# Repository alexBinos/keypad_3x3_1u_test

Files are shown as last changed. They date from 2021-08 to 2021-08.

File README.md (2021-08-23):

# keypad_3x3_1u_test

Sharing progress on the 3x3 macro keypad...

## Assembly notes

1. RGB LEDs
   - Pin 1 is marked on the PCB in silkscreen, note that the odd pin on the LED package is GND (pin 3).
   - The LEDs are designed to be placed on the back side of the PCB, facing towards the front, through the cut out.
   - To assist PCB routing, **not all LEDs are oriented in the same direction**, pay close attention to the pin 1 markings on each LED footprint.
   - The cutouts for the bottom most LEDs (D13, D16, D19) was deliberately made 0.4mm wider than the others to test the PCB footprint. This footprint wont be used on future designs.

<br/>

2. Component orientations
   - The pin 1 marker on the KC2016K 16MHz crystal oscillator (X1) and the SRV05-4 TVS diode array (U3) were not placed.
   - With the USB connector facing up:
      - Pin 1 of X1 is the **top right** pad.
      - Pin 1 of U3 is the **top left** pad.

<br/>

3. Entering the bootloader
   - Through the ISP interface, disable the HWBE fuse and enable the BOOTRST fuse.
   - Flash the Caterina bootloader
   - See section 27 of the ATMEGA32U4 datasheet for more details.

<br/>

4. Non-critical hardware bugs
   - The series termination resistor for the RGB LEDs was not placed, the LEDS still work but this may affect their reliability.
   - Pads for the reset switch are slightly too small for the switch provided but you can still make it fit

<br/>

5. If you find any more issues or have feedback for the next revision let me know

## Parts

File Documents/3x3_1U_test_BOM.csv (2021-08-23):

Id | Designator | Package | Quantity | Designation
1 | SW11 | SW_SPST_B3U-1000P | 1 | SW_Push
2 | U2 | TCR2EF33_SOT25 | 1 | TCR2EF33
3 | FB3 FB2 FB1 | L_0805_2012Metric | 3 | Ferrite_Bead
4 | D19 D16 D13 D18 D17 D15 D12 D11 D14 | SK6812-MINI-E | 9
5 | L1 | SMM2012E | 1 | L_Core_Iron_Coupled_1423
6 | J2 | USB_C_Receptacle_GCT_USB4085 | 1 | USB_C_Receptacle_USB2.0
7 | X1 | KC2016K | 1 | KC2016K
8 | U3 | SOT-23-6 | 1 | SRV05-4
9 | U1 | TQFP-44_10x10mm_P0.8mm | 1 | ATmega32U4-AU
10 | TP3 TP2 TP1 | TestPoint_Pad_D1.0mm | 3 | TestPoint
11 | SW9 SW8 SW7 SW6 SW5 SW4 SW3 SW2 SW1 | CherryMX_1.00u_PCB_KailhSocket | 9
12 | SW10 | RotaryEncoder_Alps_EC11E-Switch_Vertical_H20mm | 1 | Rotary_Encoder_Switch
13 | R17 R16 R8 R5 | R_0603_1608Metric | 3 | 330R
14 | R15 R14 | R_0603_1608Metric | 2 | 22R
15 | R13 R12 | R_0603_1608Metric | 2 | OPT
16 | R11 R9 | R_0603_1608Metric | 2 | 5K1
17 | R10 R7 R6 R4 R3 | R_0603_1608Metric | 5 | 1K
18 | R2 R1 | R_0603_1608Metric | 2 | 10K
19 | J1 | PinHeader_2x03_P2.54mm_Vertical_SMD | 1 | Conn_02x03_Odd_Even
20 | D22 D21 D20 | D_0603_1608Metric | 3 | LED
21 | D10 D9 D8 D7 D6 D5 D4 D3 D2 D1 | D_SOD-323 | 10
22 | C19 C15 C14 C13 C11 C10 C9 C8 C7 C6 C5 C4 C3 C2 C1 | C_0603_1608Metric | 15 | 100nF
23 | C18 C16 C12 | C_0603_1608Metric | 3 | 1uF
24 | C17 | C_0603_1608Metric | 1 | 10uF

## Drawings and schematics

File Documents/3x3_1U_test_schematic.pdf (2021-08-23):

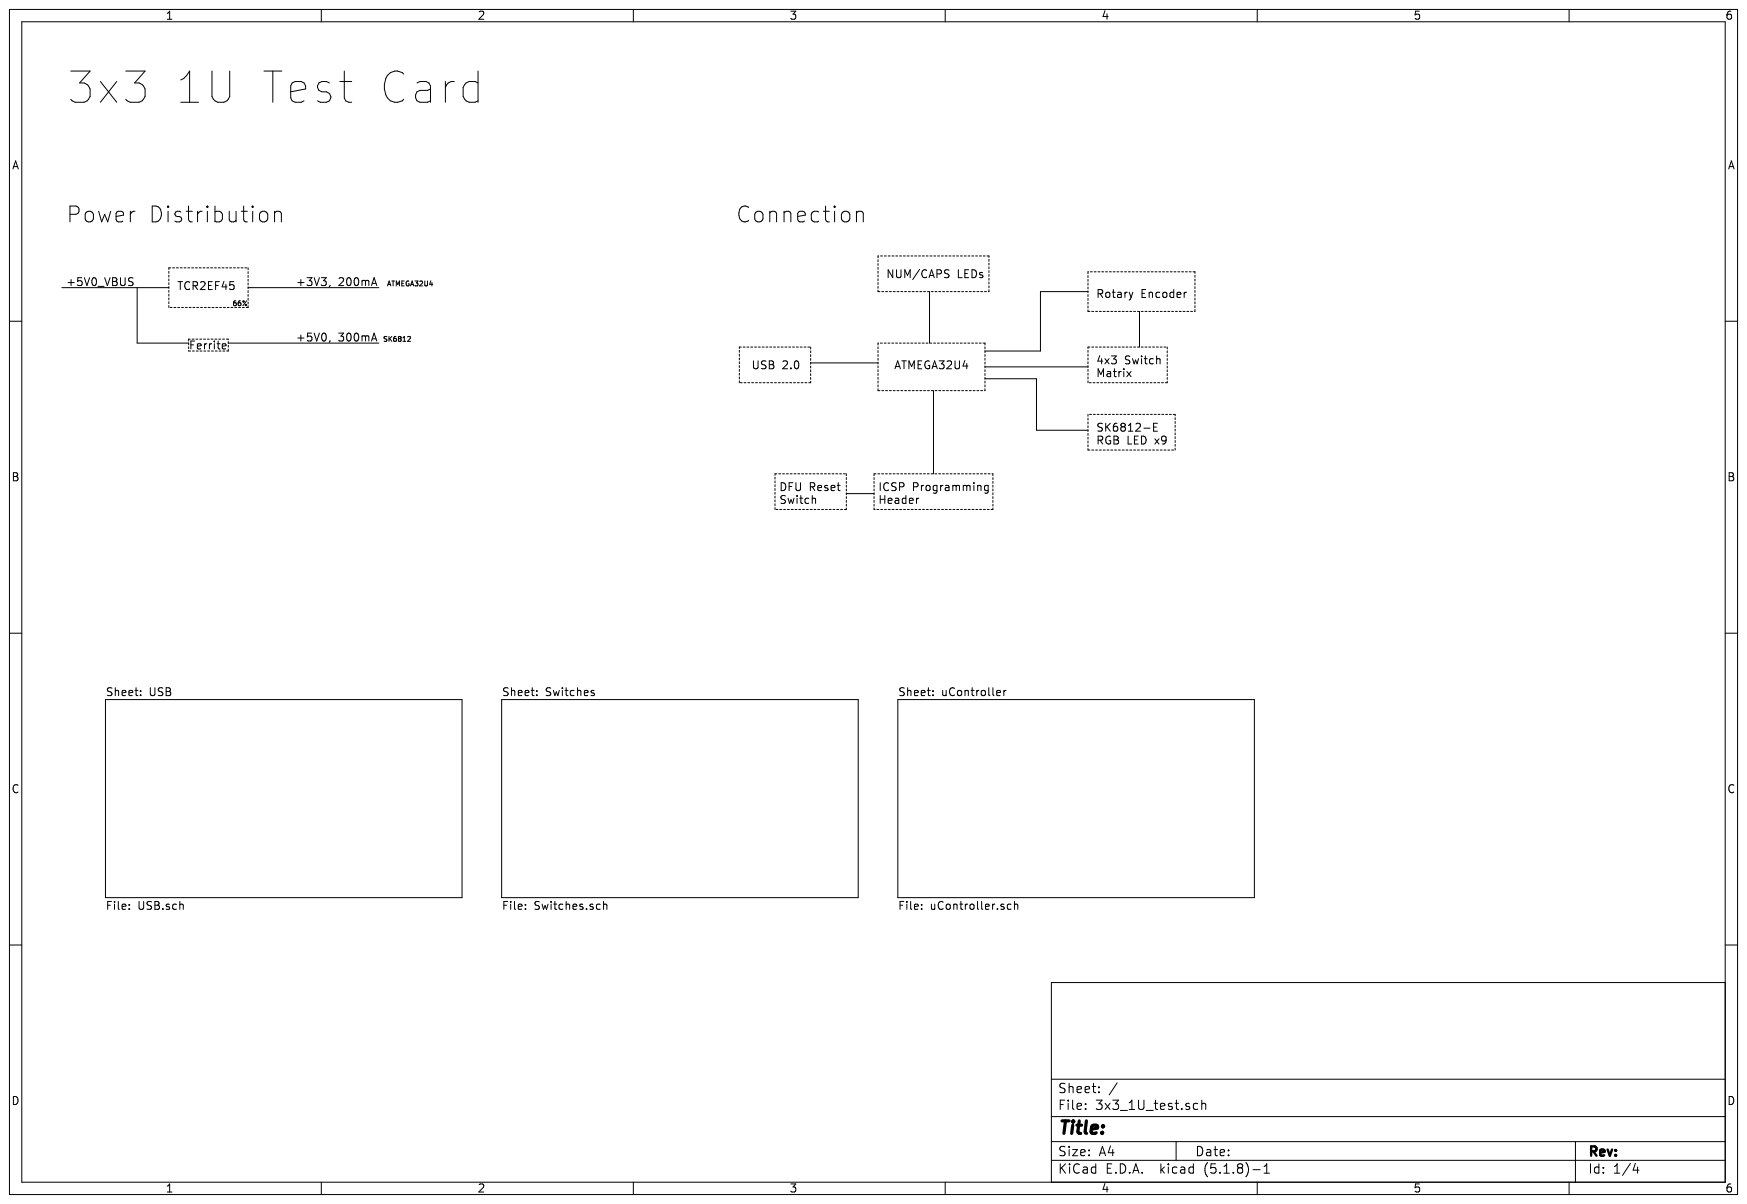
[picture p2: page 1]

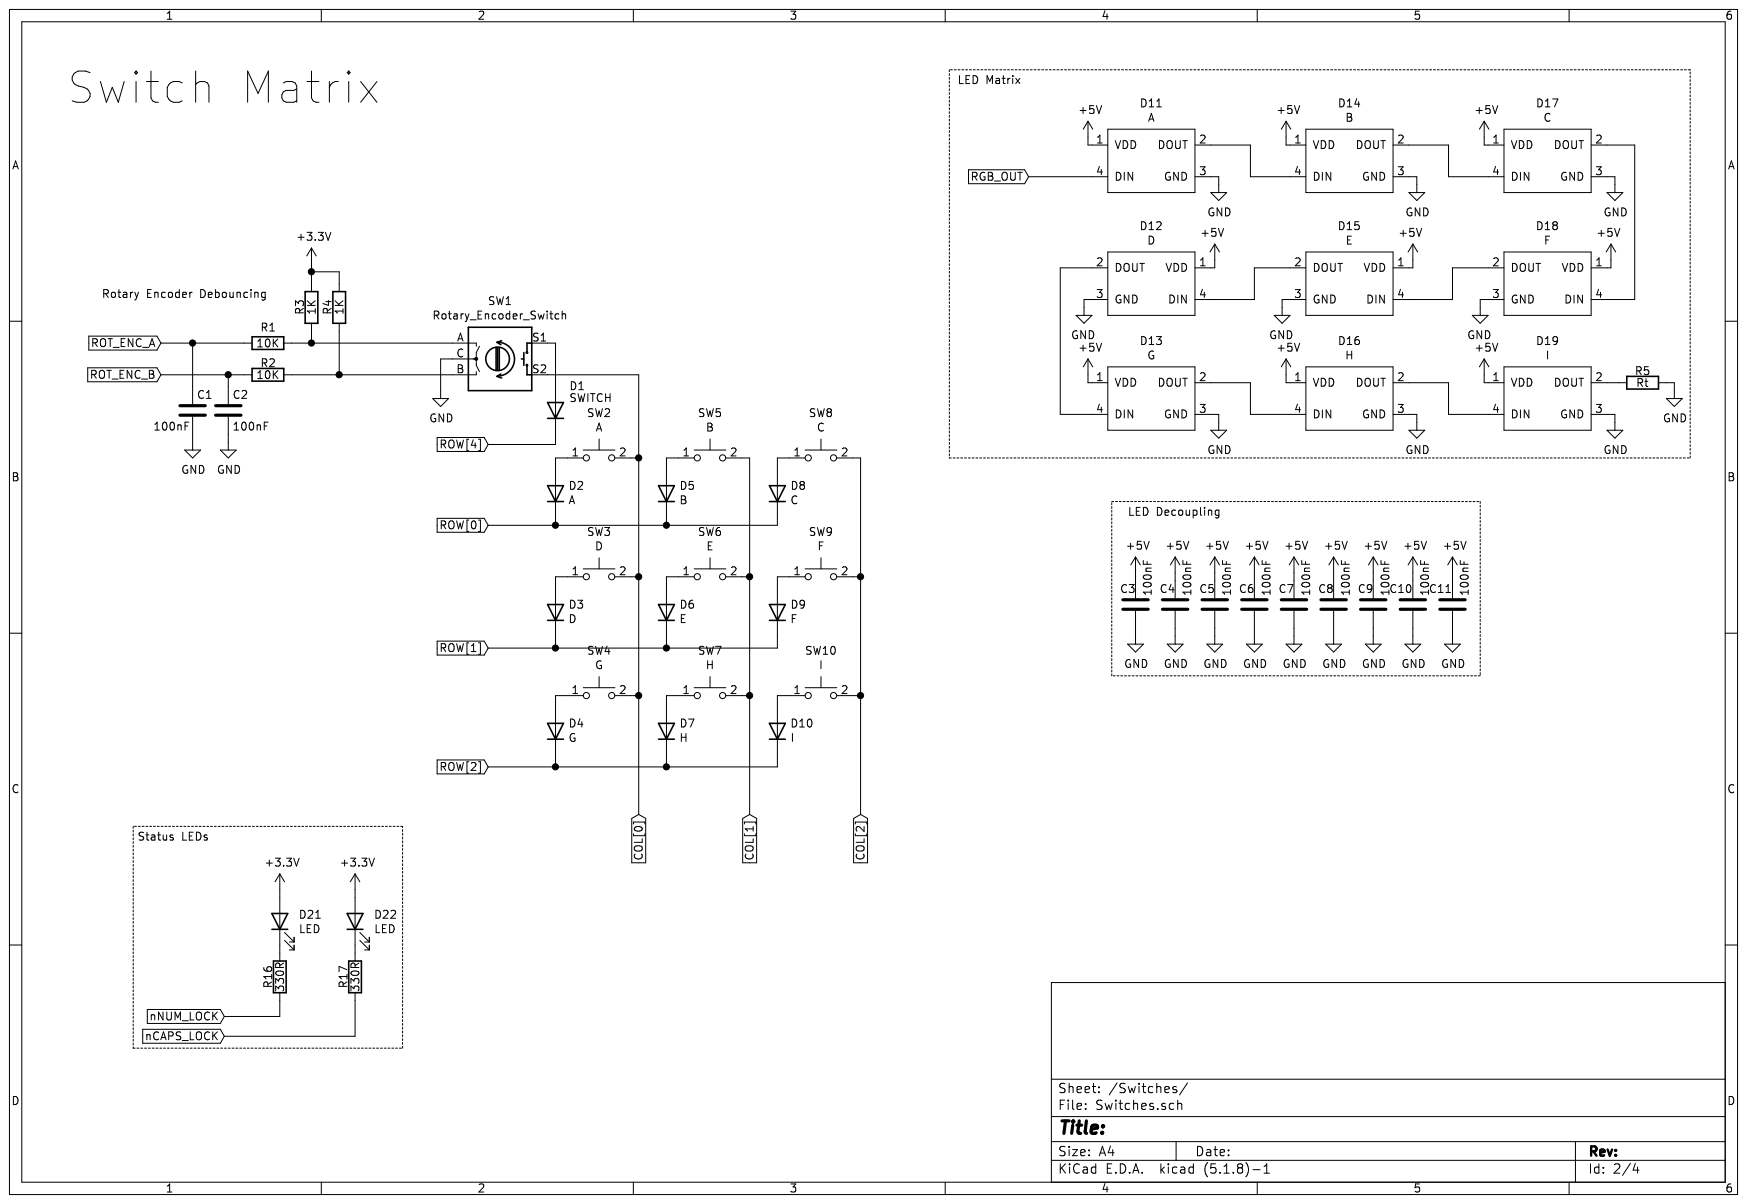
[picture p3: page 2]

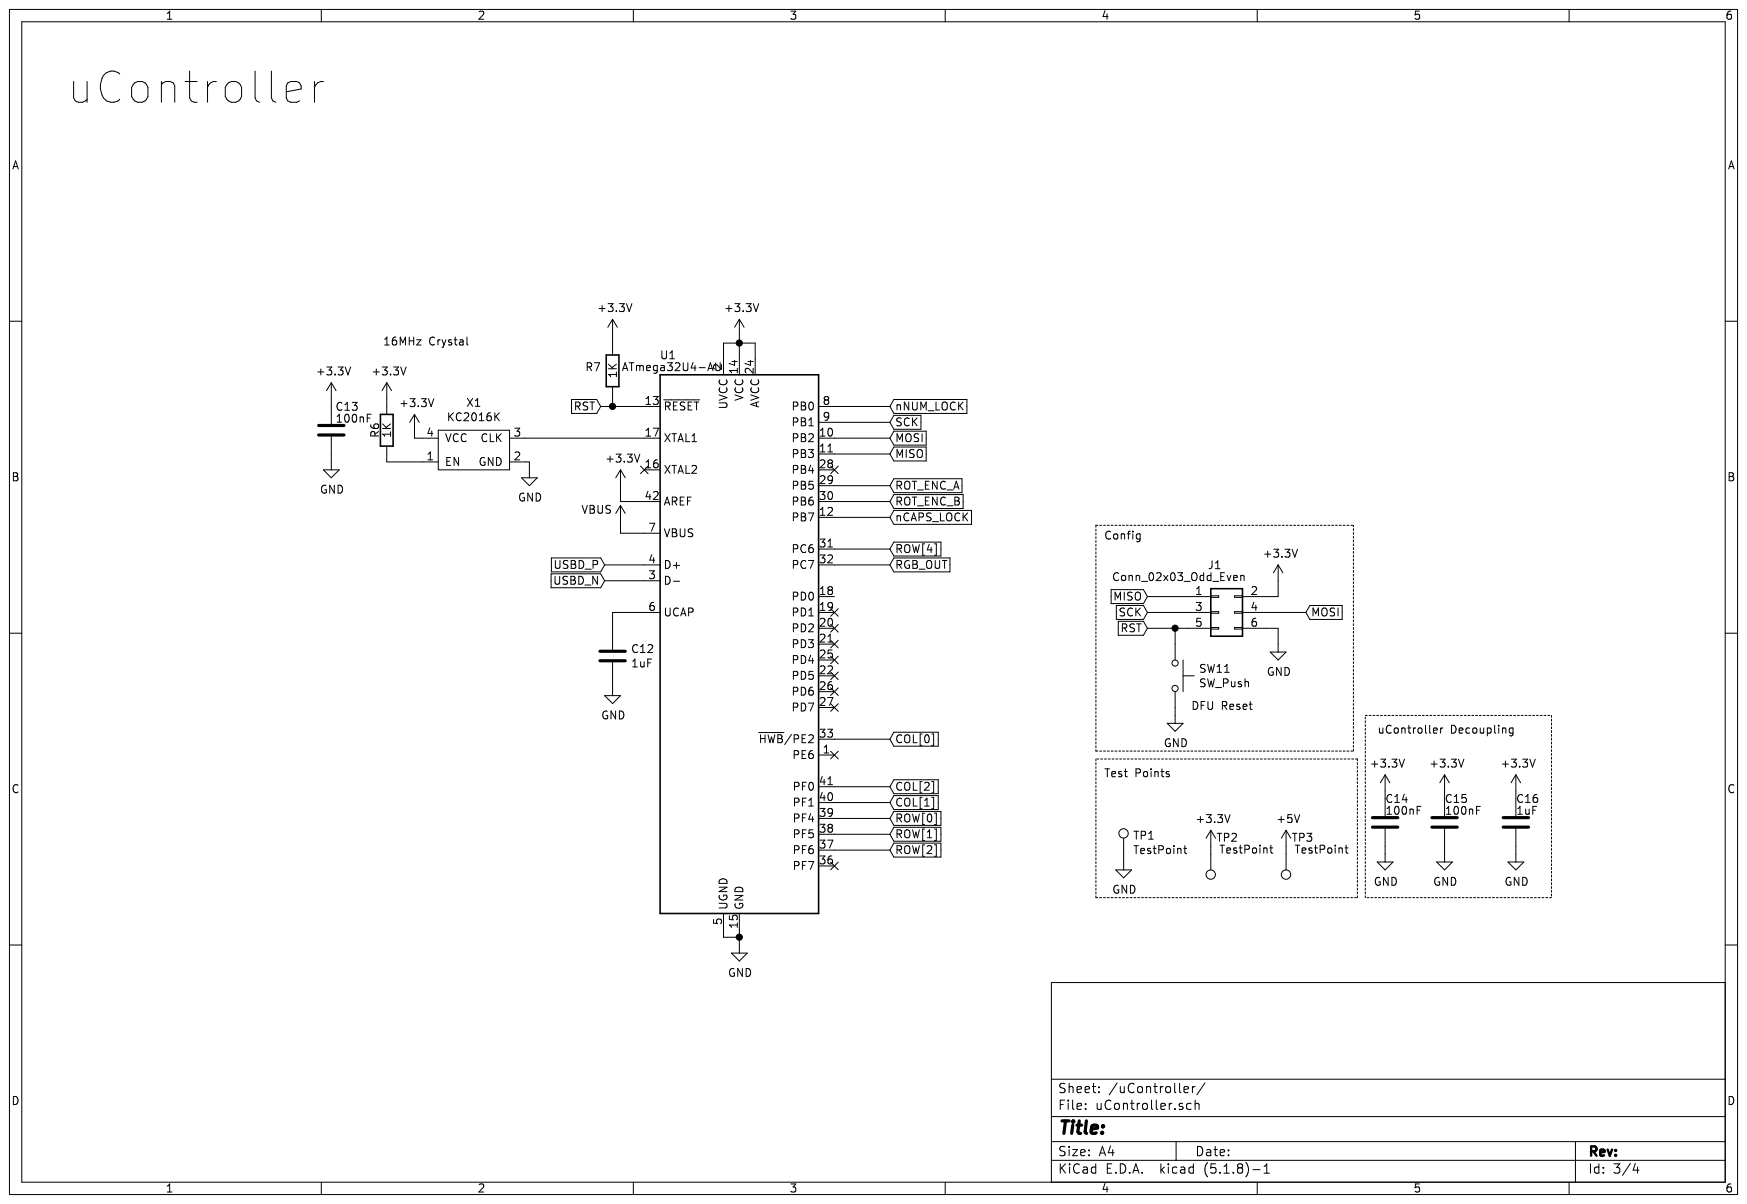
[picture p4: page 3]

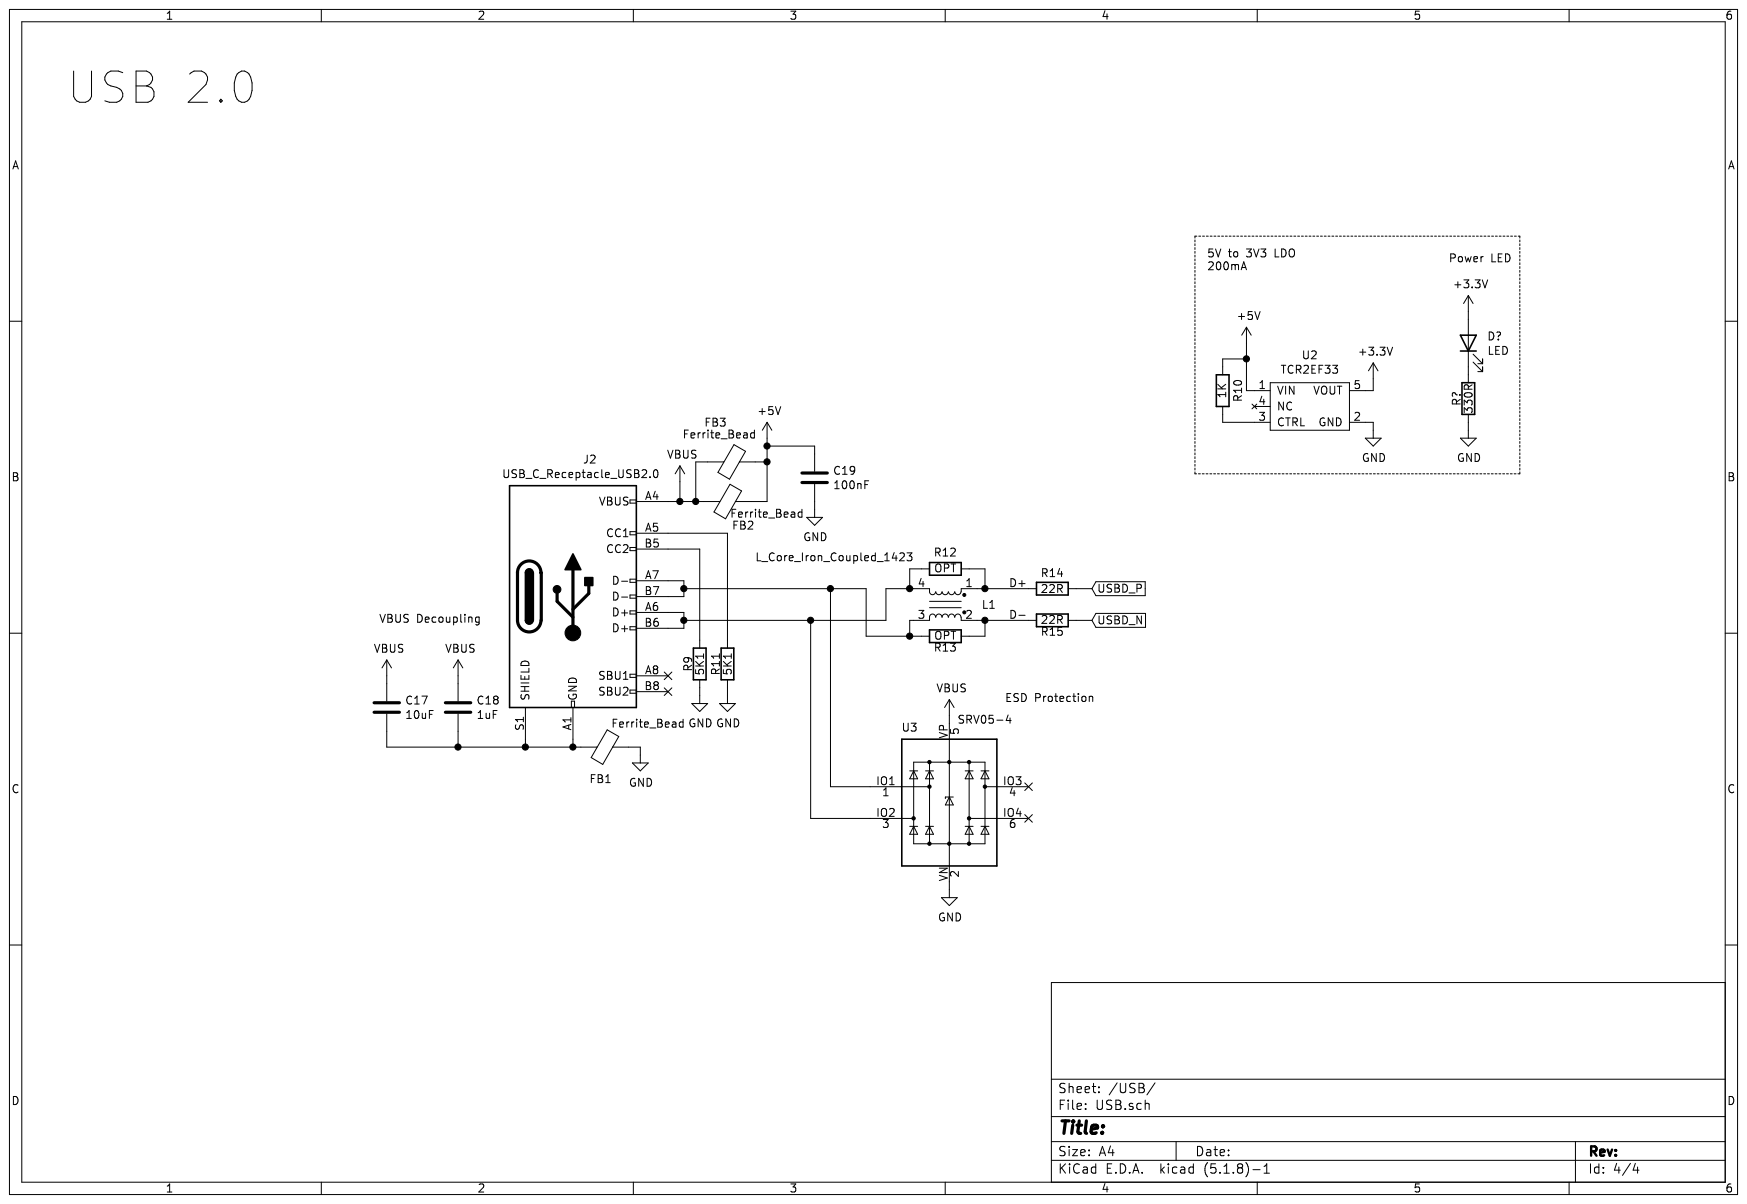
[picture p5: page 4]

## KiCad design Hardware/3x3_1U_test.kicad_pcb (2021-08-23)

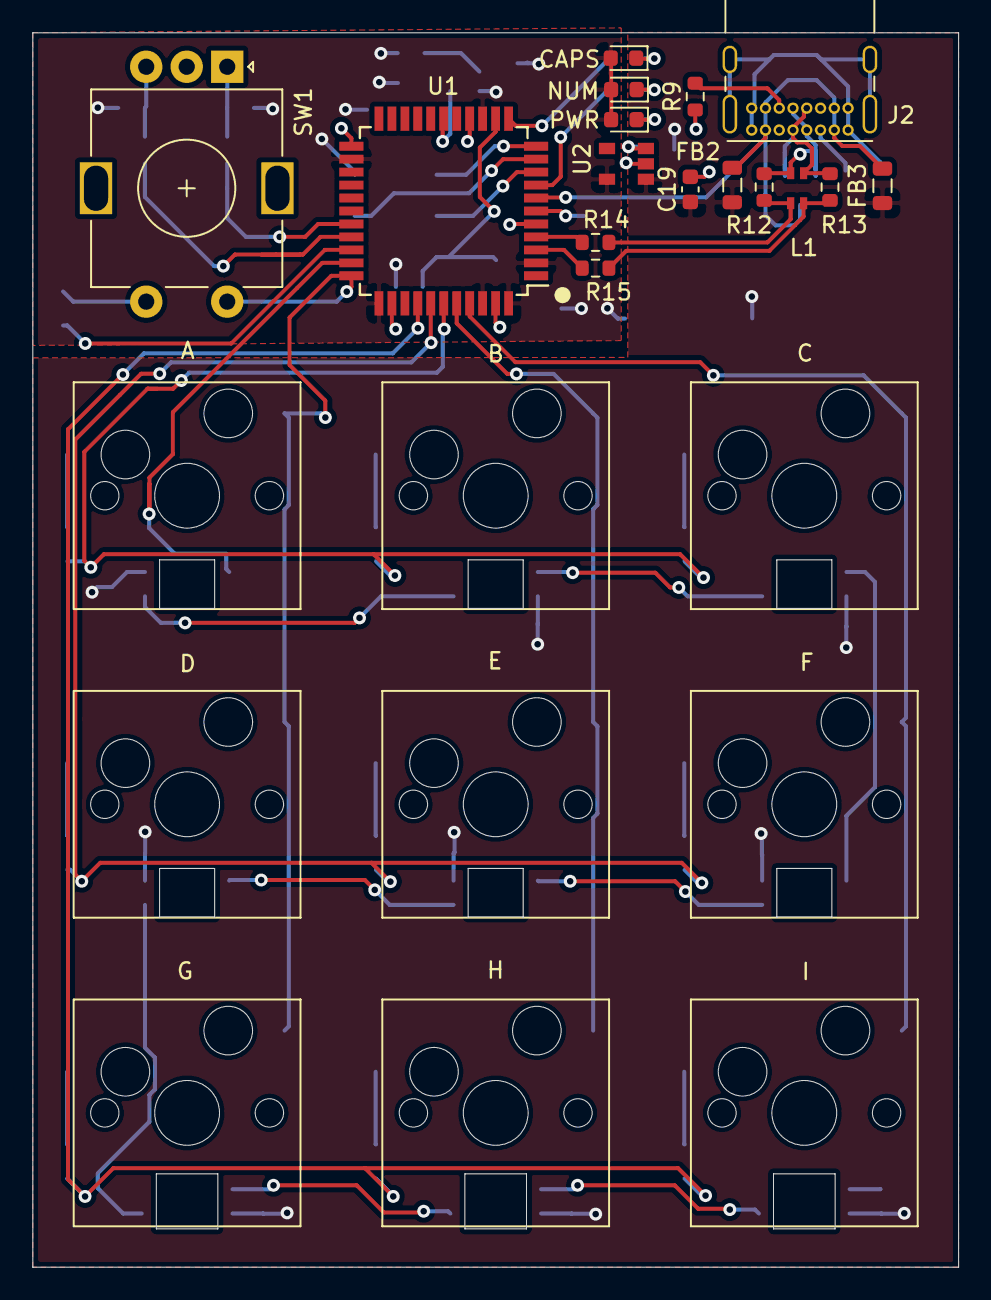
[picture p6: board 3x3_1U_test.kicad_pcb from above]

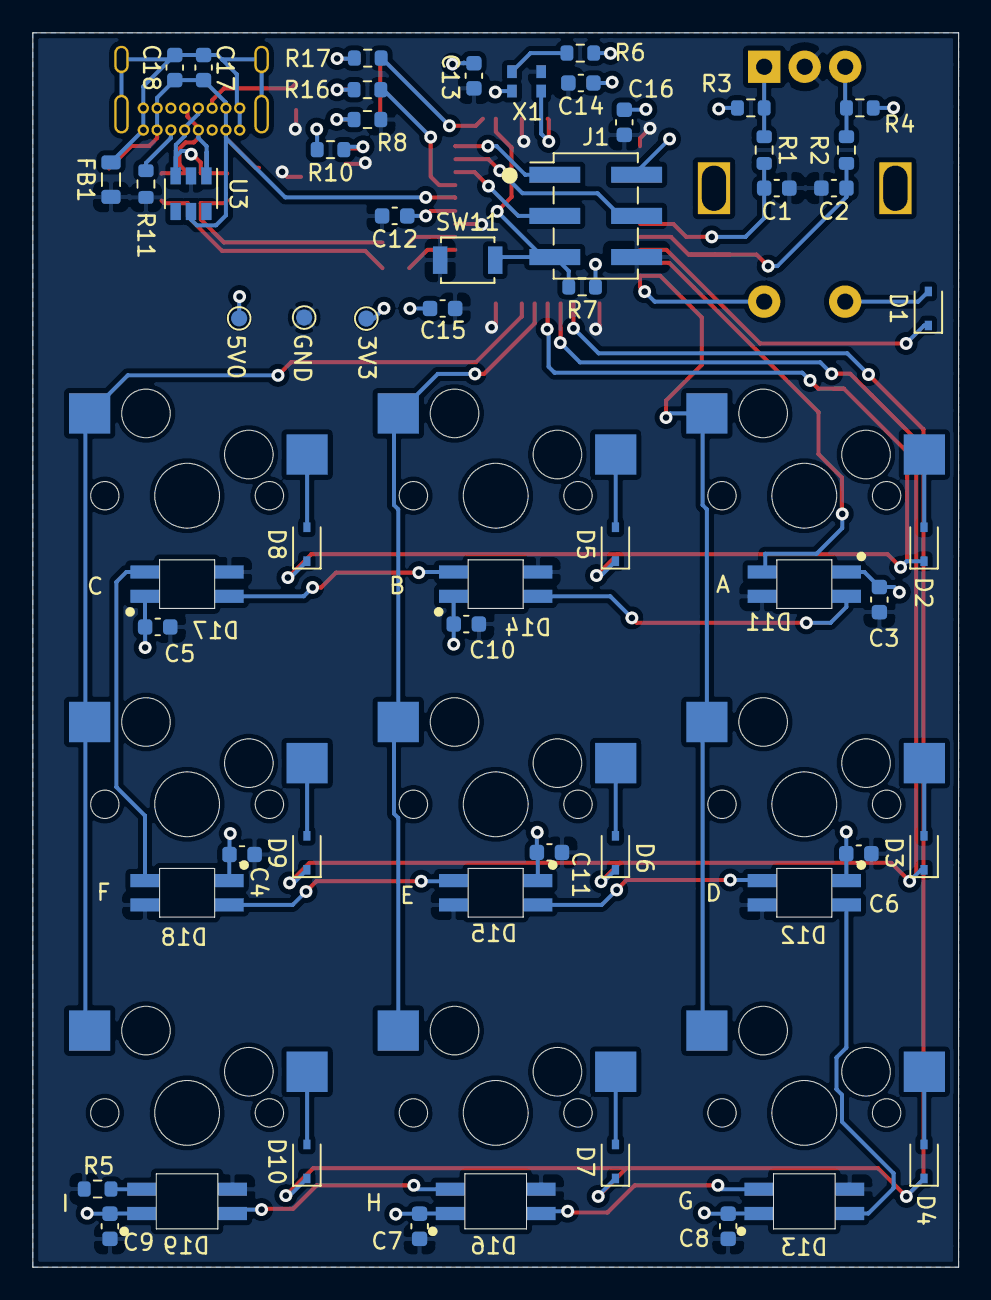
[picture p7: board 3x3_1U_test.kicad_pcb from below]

Board: 2 copper layers, 57.2 x 76.2 mm, 82 parts (48 on the bottom side), 57 nets.

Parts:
C1, C2, C3, C4, C5, C6, C7, C8, C9, C10, C11, C13, C14, C15, C19: 100nF; C_0603_1608Metric
C12, C16, C18: 1uF; C_0603_1608Metric
C17: 10uF; C_0603_1608Metric
D1: SWITCH; D_SOD-323
D2: A; D_SOD-323
D3: D; D_SOD-323
D4: G; D_SOD-323
D5: B; D_SOD-323
D6: E; D_SOD-323
D7: H; D_SOD-323
D8: C; D_SOD-323
D9: F; D_SOD-323
D10: I; D_SOD-323
D11: A; SK6812-MINI-E
D12: D; SK6812-MINI-E
D13: G; SK6812-MINI-E_0.4
D14: B; SK6812-MINI-E
D15: E; SK6812-MINI-E
D16: H; SK6812-MINI-E_0.4
D17: C; SK6812-MINI-E
D18: F; SK6812-MINI-E
D19: I; SK6812-MINI-E_0.4
D20, D21, D22: LED; D_0603_1608Metric
FB1, FB2, FB3: Ferrite_Bead; L_0805_2012Metric
J1: Conn_02x03_Odd_Even; PinHeader_2x03_P2.54mm_Vertical_SMD
J2: USB_C_Receptacle_USB2.0; USB_C_Receptacle_GCT_USB4085
L1: L_Core_Iron_Coupled_1423; SMM2012E
R1, R2: 10K; R_0603_1608Metric
R3, R4, R6, R7, R10: 1K; R_0603_1608Metric
R5: Rt; R_0603_1608Metric
R8, R16, R17: 330R; R_0603_1608Metric
R9, R11: 5K1; R_0603_1608Metric
R12, R13: OPT; R_0603_1608Metric
R14, R15: 22R; R_0603_1608Metric
SW1: Rotary_Encoder_Switch; RotaryEncoder_Alps_EC11E-Switch_Vertical_H20mm
SW2: A; CherryMX_1.00u_PCB_KailhSocket
SW3: D; CherryMX_1.00u_PCB_KailhSocket
SW4: G; CherryMX_1.00u_PCB_KailhSocket
SW5: B; CherryMX_1.00u_PCB_KailhSocket
SW6: E; CherryMX_1.00u_PCB_KailhSocket
SW7: H; CherryMX_1.00u_PCB_KailhSocket
SW8: C; CherryMX_1.00u_PCB_KailhSocket
SW9: F; CherryMX_1.00u_PCB_KailhSocket
SW10: I; CherryMX_1.00u_PCB_KailhSocket
SW11: SW_Push; SW_SPST_B3U-1000P
TP1, TP2, TP3: TestPoint; TestPoint_Pad_D1.0mm
U1: ATmega32U4-AU; TQFP-44_10x10mm_P0.8mm
U2: TCR2EF33; TCR2EF33_SOT25
U3: SRV05-4; SOT-23-6
X1: KC2016K

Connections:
+3V3: C13.1, C14.1, C15.1, C16.1, D20.2, D21.2, D22.2, J1.2, R3.1, R4.1, R6.2, R7.1, TP2.1, U1.2, U1.14, U1.24, U1.34, U1.42, U1.44, U2.5, X1.4
+5V: C3.1, C4.1, C5.1, C6.1, C7.1, C8.1, C9.1, C10.1, C11.1, C19.1, D11.1, D12.1, D13.1, D14.1, D15.1, D16.1, D17.1, D18.1, D19.1, FB2.1, FB3.1, R10.2, TP3.1, U2.1
/USB/D+: L1.1, R12.1, R14.2
/USB/D-: L1.2, R13.1, R15.2
COL[0]: SW1.S2, SW2.2, SW3.2, SW4.2, U1.33
COL[1]: SW5.2, SW6.2, SW7.2, U1.40
COL[2]: SW8.2, SW9.2, SW10.2, U1.41
GND: C1.2, C2.2, C3.2, C4.2, C5.2, C6.2, C7.2, C8.2, C9.2, C10.2, C11.2, C12.2, C13.2, C14.2, C15.2, C16.2, C19.2, D11.3, D12.3, D13.3, D14.3, D15.3, D16.3, D17.3, D18.3, D19.3, FB1.1, J1.6, R5.2, R8.1, R9.1, R11.1, SW1.C, SW11.2, TP1.1, U1.5, U1.15, U1.23, U1.35, U1.43, U2.2, U3.2, X1.2
MISO: J1.1, U1.11
MOSI: J1.4, U1.10
unnamed: C12.1, U1.6
unnamed: C17.2, C18.2, FB1.2, J2.A1, J2.A12, J2.B1, J2.B12, J2.S1
unnamed: D1.2, SW1.S1
unnamed: D2.2, SW2.1
unnamed: D3.2, SW3.1
unnamed: D4.2, SW4.1
unnamed: D5.2, SW5.1
unnamed: D6.2, SW6.1
unnamed: D7.2, SW7.1
unnamed: D8.2, SW8.1
unnamed: D9.2, SW9.1
unnamed: D10.2, SW10.1
unnamed: D11.2, D14.4
unnamed: D12.2, D13.4
unnamed: D12.4, D15.2
unnamed: D13.2, D16.4
unnamed: D14.2, D17.4
unnamed: D15.4, D18.2
unnamed: D16.2, D19.4
unnamed: D17.2, D18.4
unnamed: D19.2, R5.1
unnamed: D20.1, R8.2
unnamed: D21.1, R16.2
unnamed: D22.1, R17.2
unnamed: J2.A5, R11.2
unnamed: J2.A6, J2.B6, L1.4, R12.2, U3.3
unnamed: J2.A7, J2.B7, L1.3, R13.2, U3.1
unnamed: J2.B5, R9.2
unnamed: R1.1, R3.2, SW1.A
unnamed: R2.1, R4.2, SW1.B
unnamed: R6.1, X1.1
unnamed: R10.1, U2.3
unnamed: U1.17, X1.3
RGB_OUT: D11.4, U1.32
ROT_ENC_A: C1.1, R1.2, U1.29
ROT_ENC_B: C2.1, R2.2, U1.30
ROW[0]: D2.1, D5.1, D8.1, U1.39
ROW[1]: D3.1, D6.1, D9.1, U1.38
ROW[2]: D4.1, D7.1, D10.1, U1.37
ROW[4]: D1.1, U1.31
RST: J1.5, R7.2, SW11.1, U1.13
SCK: J1.3, U1.9
USBD_N: R15.1, U1.3
USBD_P: R14.1, U1.4
VBUS: C17.1, C18.1, FB2.2, FB3.2, J2.A4, J2.A9, J2.B4, J2.B9, U1.7, U3.5
nCAPS_LOCK: R17.1, U1.12
nNUM_LOCK: R16.1, U1.8

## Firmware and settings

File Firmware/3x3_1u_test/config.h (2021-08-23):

#pragma once

#include "config_common.h"

/* USB Device descriptor parameter */
#define VENDOR_ID       0x1234
#define PRODUCT_ID      0x5678
#define DEVICE_VER      0x0000
#define MANUFACTURER    Alex Binos
#define PRODUCT         3x3_1u_test

/* Switch matrix dimensions */
#define MATRIX_ROWS 4
#define MATRIX_COLS 3

/* Micro controller pins */
#define MATRIX_ROW_PINS { F4, F5, F6, C6}
#define MATRIX_COL_PINS { E2, F1, F0}
#define UNUSED_PINS { B4, D0, D1, D2, D3, D4, D5, D6, D7, E6, F7 }

/* COL2ROW, ROW2COL*/
#define DIODE_DIRECTION COL2ROW

/* RGB array */
#define RGB_DI_PIN C7
#define RGBLED_NUM 9
#define RGBLIGHT_HUE_STEP 8         // HSV steps for animations
#define RGBLIGHT_SAT_STEP 8
#define RGBLIGHT_VAL_STEP 8
#define RGBLIGHT_LIMIT_VAL 128      // Half brightness to save power
#define RGBLIGHT_DEFAULT_HUE 85     // Green in HSV
#define RGBLIGHT_DEFAULT_MODE RGBLIGHT_MODE_RGB_TEST
#define RGBLIGHT_ANIMATIONS         // For more options see: https://beta.docs.qmk.fm/using-qmk/hardware-features/lighting/feature_rgblight

/* Indicator LEDs (active low) */
#define LED_NUM_LOCK_PIN B0
#define LED_CAPS_LOCK_PIN B7
#define LED_PIN_ON_STATE 0

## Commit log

2021-07-29 Initial commit- adding design files and datasheets
    [3x3_1U_test.kicad_pcb, 3x3_1U_test.sch, Switches.sch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]
2021-07-29 Adding BOM file
    [3x3_1U_test_BOM.csv]
2021-08-03 Updating readme to include assembly notes
